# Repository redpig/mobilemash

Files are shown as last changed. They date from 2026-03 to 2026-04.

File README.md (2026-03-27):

# MobileMash - ESP32 Phone Button Presser

A 3D-printable, ESP32-controlled servo harness for programmatically pressing
phone buttons. Primary use case: booting phones into fastboot mode unattended.

## Supported Phones

| Phone | Status |
|---|---|
| Pixel 10 Pro | v1 |

## How It Works

Two SG90 micro servos are mounted in a 3D-printed cradle that clips around the
phone. Each servo has a small arm that presses a button (power, volume-down).
An ESP32 dev board drives the servos and accepts commands over USB serial.

### Fastboot Sequence

1. **Force shutdown** - Press and hold power for up to 30 seconds (or until
   told to release).
2. **Enter fastboot** - Hold volume-down, then briefly press power. Release
   when told or after a safety timeout.

## Hardware BOM

| Part | Qty | Notes |
|---|-----|---|
| ESP32 DevKit v1 (or similar) | 1 | Any ESP32 board with USB |
| SG90 micro servo | 2 | 9g, 180-degree |
| M2x8 self-tapping screws | 4 | Mount servos to cradle |
| Rubber/silicone bumper pads | 2 | Glue to servo arms for grip |
| USB-A to micro-USB cable | 1 | Power + data to ESP32 |
| 470uF electrolytic capacitor | 1 | Optional, across servo 5V/GND |

## Wiring

```
ESP32 GPIO 13 --> Power servo signal (orange)
ESP32 GPIO 14 --> Volume-down servo signal (orange)
ESP32 5V      --> Both servo VCC (red)
ESP32 GND     --> Both servo GND (brown)
```

## Firmware

Built with PlatformIO (Arduino framework).

```bash
cd firmware
pio run -t upload
```

### Serial Protocol (115200 baud)

Commands are newline-terminated ASCII:

| Command | Description |
|---|---|
| `PRESS_POWER <ms>` | Press power button for `<ms>` milliseconds |
| `PRESS_VOLDN <ms>` | Press volume-down for `<ms>` milliseconds |
| `FASTBOOT [shutdown_ms] [combo_ms]` | Run full fastboot entry sequence |
| `RELEASE_ALL` | Immediately release all buttons |
| `STATUS` | Report current state |
| `PING` | Returns `PONG` |

Responses are newline-terminated:

| Response | Meaning |
|---|---|
| `OK <detail>` | Command accepted / completed |
| `ERR <detail>` | Error |
| `STATE <json>` | Status response |
| `PONG` | Ping reply |

## 3D Printing

OpenSCAD source in `cad/`. Export STL and print with:
- Material: PLA or PETG
- Layer height: 0.2mm
- Infill: 20%+
- Supports: not required

## Host Tool

```bash
pip install pyserial
python host/mobilemash_cli.py --port /dev/ttyUSB0 fastboot
```

## License

Apache 2.0

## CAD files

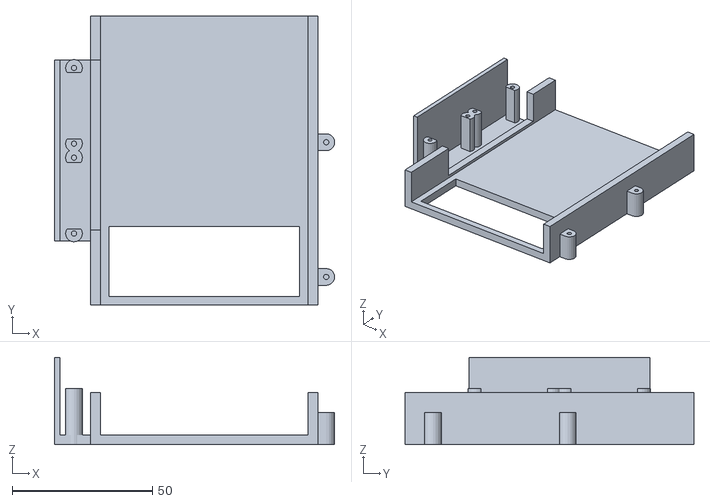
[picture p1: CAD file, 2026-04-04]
cad/pixel10pro_cradle.stl
99.9 x 103.0 x 31.1

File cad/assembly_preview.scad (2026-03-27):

/*
 * Assembly preview — cradle + phone + servos + ESP32
 * Uses $t (0–1) for animation rotation.
 */

use <pixel10pro_cradle.scad>

phone_w = 72; phone_h = 152.8; phone_d = 8.6;
clearance = 1.0; wall = 3.5; lip_h = 15;
cradle_len = 90; cradle_y_offset = 20;

sg90_body_w = 22.7; sg90_body_d = 11.8; sg90_body_h = 22.2;
sg90_tab_w = 32.5; sg90_tab_h = 2.5; sg90_shaft_offset = 6;
sg90_flipped_tab_z = 6.7; sg90_arm_drop = 4; sg90_shaft_protrusion = 5;
sg90_screw_spacing = 27;

inner_w = phone_w + 2 * clearance;
outer_w = inner_w + 2 * wall;
wall_top = wall + lip_h;

power_btn_y = 40; voldn_btn_y = 60;

arm_z = wall + phone_d / 2;
servo_bottom_z = arm_z + sg90_arm_drop;
boss_height = servo_bottom_z + sg90_flipped_tab_z;
boss_x = -(sg90_body_d / 2);

module phone() {
    color([0.15, 0.15, 0.15, 0.7])
        translate([wall + clearance, -cradle_y_offset, wall])
            cube([phone_w, phone_h, phone_d]);
    color([0.1, 0.1, 0.1, 0.8])
        translate([wall + clearance + 2, -cradle_y_offset + 10, wall - 3])
            cube([phone_w - 4, 26, 3]);
}

module sg90_servo(btn_y) {
    local_y = btn_y - cradle_y_offset;
    tab_z = servo_bottom_z + sg90_flipped_tab_z;

    // Body sits outside the left wall
    servo_x = -sg90_body_d;
    shaft_x = servo_x + sg90_body_d / 2;
    shaft_y = local_y;

    // Body below tabs
    color([0.2, 0.4, 0.8, 0.85])
        translate([servo_x, local_y - sg90_body_w/2, servo_bottom_z])
            cube([sg90_body_d, sg90_body_w, sg90_flipped_tab_z]);

    // Body above tabs
    color([0.2, 0.4, 0.8, 0.85])
        translate([servo_x, local_y - sg90_body_w/2, tab_z + sg90_tab_h])
            cube([sg90_body_d, sg90_body_w,
                  sg90_body_h - sg90_flipped_tab_z - sg90_tab_h]);

    // Tab ears
    color([0.25, 0.45, 0.85, 0.85])
        for (dy = [local_y - sg90_tab_w/2, local_y + sg90_body_w/2])
            translate([servo_x, dy, tab_z])
                cube([sg90_body_d, (sg90_tab_w - sg90_body_w)/2, sg90_tab_h]);

    // Gear housing + shaft
    color([0.2, 0.4, 0.8])
        translate([shaft_x, shaft_y, servo_bottom_z - 2])
            cylinder(h = 2, d = 8, $fn = 20);
    color([1, 1, 1])
        translate([shaft_x, shaft_y, servo_bottom_z - sg90_shaft_protrusion])
            cylinder(h = 3, d = 5, $fn = 20);

    // Arm at button height — pointing toward phone (+X)
    arm_len = 17; press_angle = 30;
    color([1, 1, 1])
        translate([0, 0, arm_z - 1])
            hull() {
                translate([shaft_x, shaft_y, 0])
                    cylinder(h = 2, d = 4, $fn = 16);
                translate([shaft_x + arm_len * cos(press_angle),
                           shaft_y - arm_len * sin(press_angle), 0])
                    cylinder(h = 2, d = 3, $fn = 16);
            }
}

module esp32_board() {
    board_x = outer_w + 3 - 25;
    color([0.0, 0.5, 0.0, 0.85])
        translate([outer_w + 3 - 14, 10, wall + 8]) cube([28, 55, 1.6]);
    color([0.7, 0.7, 0.7])
        translate([outer_w + 3 - 5, 10 - 1, wall + 9.6]) cube([10, 8, 3.5]);
    color([0.7, 0.7, 0.7])
        translate([outer_w + 3 - 10, 10 + 36, wall + 9.6]) cube([18, 16, 3]);
}

rot = $t * 360;
rotate([0, 0, rot])
translate([-outer_w / 2, -cradle_len / 2, -wall_top / 2]) {
    mobilemash_cradle();
    phone();
    sg90_servo(power_btn_y);
    sg90_servo(voldn_btn_y);
    esp32_board();
}

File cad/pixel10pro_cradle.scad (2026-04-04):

/*
 * MobileMash – 3D-printable cradle for Pixel 10 Pro
 *
 * Two SG90 micro servos mount UPSIDE-DOWN (shaft pointing down) on
 * screw bosses outside the LEFT wall (phone is face-down, so the
 * right-side buttons face the left wall).
 *
 * A base shelf at tray level connects the bosses to the wall.
 * Boss height is calculated so the servo arm sweeps in XY at
 * phone-button height.
 *
 * No print supports needed.  Sits flat.
 *
 * Phone dimensions (Pixel 10 Pro):
 *   152.8 x 72 x 8.6 mm
 *   Camera bump: 3 mm protrusion, starts 10 mm from top, ~25 mm tall,
 *                2 mm inset from each side edge.
 *
 * Button layout (right side of phone, measured from top):
 *   Power button center:      ~50 mm from top
 *   Volume-down button center: ~78 mm from top (50 + 28)
 *
 * SG90 servo body: 22.2 x 11.8 x 22.7 mm  (h x d x w)
 * SG90 mounting tabs: 32.5 mm total (tab-to-tab along body w)
 * SG90 screw hole spacing: 27 mm (measured)
 * Measured: 13 mm from tab screw-hole center to shaft tip.
 *
 * Print settings:
 *   Layer height: 0.2 mm
 *   Infill: 20%+
 *   Material: PLA or PETG
 *   Supports: NOT needed
 *
 * SPDX-License-Identifier: Apache-2.0
 */

// ── Tunables ────────────────────────────────────────────────────────────

phone_w   = 72;
phone_h   = 152.8;
phone_d   = 8.6;

clearance = 1.0;

wall = 3.5;
lip_h = 15;

cradle_y_offset = 7;   // start 7 mm from phone top to fully enclose camera bump
cradle_len = 103;      // extended to maintain same coverage at bottom

// ── Camera bump (Pixel 10 Pro) ──────────────────────────────────────────
cam_bump_protrusion = 3;
cam_bump_from_top   = 10;
cam_bump_height     = 25;
cam_bump_inset      = 2;
cam_bump_y_start = max(0, cam_bump_from_top - cradle_y_offset);
cam_bump_y_end   = cam_bump_from_top + cam_bump_height - cradle_y_offset;
cam_bump_w       = phone_w - 2 * cam_bump_inset;

// ── SG90 servo dimensions ───────────────────────────────────────────────
sg90_body_w  = 22.7;
sg90_body_d  = 11.8;
sg90_body_h  = 22.2;
sg90_tab_w   = 32.5;
sg90_tab_h   = 2.5;
sg90_shaft_offset = 6;

sg90_flipped_tab_z = 6.7;
sg90_shaft_protrusion = 5;
sg90_arm_drop = 4;

sg90_screw_spacing = 27;

// Button positions from top of phone.
power_btn_y = 50;
voldn_btn_y = 78;

// Shift the power servo mount toward the top (lower Y) so both
// screw bosses have room.
power_mount_shift = -4;

m2_hole_d = 1.9;     // tighter hole for better screw grip
boss_d = 6;

// ── Derived values ──────────────────────────────────────────────────────
inner_w = phone_w + 2 * clearance;
outer_w = inner_w + 2 * wall;
wall_top = wall + lip_h;

arm_z = wall + phone_d / 2;
servo_bottom_z = arm_z + sg90_arm_drop;

// Boss height: +1.5 mm per user feedback.
boss_height = servo_bottom_z + sg90_flipped_tab_z + 1.5;

boss_x = -(sg90_body_d / 2);

// Clearance between boss inner face and servo body edge.
// Body is 22.7 mm; with 27 mm boss spacing, each boss inner face
// must be at least 22.7/2 = 11.35 mm from center.  Add 0.5 mm gap.
boss_inner_clearance = sg90_body_w / 2 + 0.5;  // 11.85 mm from servo center

// ── Modules ─────────────────────────────────────────────────────────────

module cradle_base() {
    difference() {
        cube([outer_w, cradle_len, wall_top]);

        translate([wall, -0.1, wall])
            cube([inner_w, cradle_len + 0.2, lip_h + 1]);

        // Camera bump through-hole — fully enclosed by base material on
        // all four sides.  Phone drops in from above; the bump passes
        // through the hole and the surrounding edges retain the phone
        // on both X and Y axes.
        if (cam_bump_y_end > cam_bump_y_start) {
            translate([wall + clearance + cam_bump_inset,
                       cam_bump_y_start,
                       -0.1])
                cube([cam_bump_w,
                      cam_bump_y_end - cam_bump_y_start,
                      wall + 0.2]);
        }
    }
}

module servo_cutout(btn_y) {
    local_y = btn_y - cradle_y_offset;
    cutout_half = sg90_tab_w / 2;

    translate([-0.1,
               local_y - cutout_half,
               arm_z - 3])
        cube([wall + 0.2,
              sg90_tab_w,
              wall_top - (arm_z - 3) + 0.1]);
}

// D-shaped boss: cylinder with the inner face cut flat so the
// servo body (22.7 mm) fits between the two bosses.
module d_boss(center_y, mount_center_y) {
    is_lower = (center_y < mount_center_y);
    // Cut plane: inner face at boss_inner_clearance from mount center
    cut_y = is_lower
        ? mount_center_y - boss_inner_clearance
        : mount_center_y + boss_inner_clearance;

    difference() {
        translate([boss_x, center_y, 0])
            cylinder(h = boss_height, d = boss_d, $fn = 20);

        // Cut the inner half to make a flat face
        if (is_lower) {
            translate([boss_x - boss_d, cut_y, -0.1])
                cube([boss_d * 2, boss_d, boss_height + 0.2]);
        } else {
            translate([boss_x - boss_d, center_y - boss_d/2, -0.1])
                cube([boss_d * 2, cut_y - (center_y - boss_d/2), boss_height + 0.2]);
        }
    }
}

module servo_mount(btn_y, mount_shift=0) {
    local_y = btn_y - cradle_y_offset + mount_shift;

    // Base shelf — extends to meet the back wall
    shelf_x_start = boss_x - 5 - 2;  // align with back wall outer edge
    shelf_w = 0 - shelf_x_start;

    translate([shelf_x_start,
               local_y - sg90_tab_w / 2,
               0])
        cube([shelf_w, sg90_tab_w, wall]);

    // D-shaped screw bosses
    for (hole_y = [local_y - sg90_screw_spacing / 2,
                   local_y + sg90_screw_spacing / 2]) {
        d_boss(hole_y, local_y);
    }
}

module servo_mount_holes(btn_y, mount_shift=0) {
    local_y = btn_y - cradle_y_offset + mount_shift;

    for (hole_y = [local_y - sg90_screw_spacing / 2,
                   local_y + sg90_screw_spacing / 2]) {
        translate([boss_x, hole_y, boss_height - 8])
            cylinder(h = 8.1, d = m2_hole_d, $fn = 20);
    }
}

// Back wall behind each servo to resist torque that pulls
// the servo away from the cradle wall.
module servo_back_wall(btn_y, mount_shift=0) {
    local_y = btn_y - cradle_y_offset + mount_shift;
    back_w = sg90_tab_w;
    back_t = 2;          // thickness
    back_h = boss_height + sg90_body_h / 2; // extend up behind servo

    // Position inner face 5 mm from boss hole center (in X, away from wall)
    back_x = boss_x - 5;
    translate([back_x - back_t,
               local_y - back_w / 2,
               0])
        cube([back_t, back_w, back_h]);
}

module esp32_mount() {
    for (dy = [10, 58]) {
        translate([outer_w + 3, dy, 0])
            difference() {
                union() {
                    cylinder(h = wall + 8, d = 6, $fn = 20);
                    translate([-3, -3, 0])
                        cube([3, 6, wall + 8]);
                }
                translate([0, 0, wall])
                    cylinder(h = 9, d = m2_hole_d, $fn = 20);
            }
    }
}

// ── Assembly ────────────────────────────────────────────────────────────

module mobilemash_cradle() {
    difference() {
        union() {
            cradle_base();
            servo_mount(power_btn_y, power_mount_shift);
            servo_mount(voldn_btn_y);
            servo_back_wall(power_btn_y, power_mount_shift);
            servo_back_wall(voldn_btn_y);
            esp32_mount();
        }

        servo_cutout(power_btn_y);
        servo_cutout(voldn_btn_y);

        servo_mount_holes(power_btn_y, power_mount_shift);
        servo_mount_holes(voldn_btn_y);
    }
}

mobilemash_cradle();

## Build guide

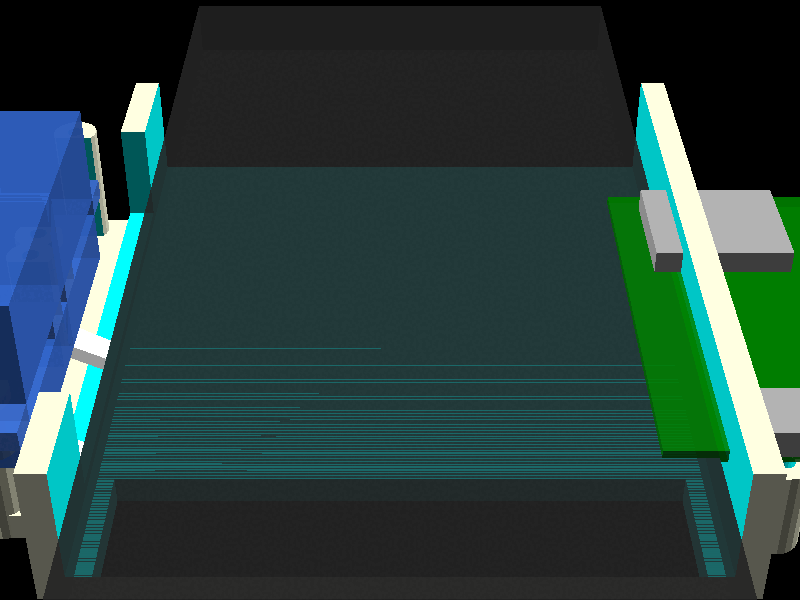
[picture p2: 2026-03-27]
cad/assembly_preview.gif

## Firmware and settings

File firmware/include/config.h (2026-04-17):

#pragma once

// ---------- Servo GPIO pins ----------
#define PIN_SERVO_POWER   13
#define PIN_SERVO_VOLDN   14

// ---------- Servo angles (degrees) ----------
// "Released" = arm is away from the button.
// "Pressed"  = arm pushes the button.
// Tune these per-build until the arm cleanly presses the button.
#define ANGLE_POWER_RELEASED  0
#define ANGLE_POWER_PRESSED   75

#define ANGLE_VOLDN_RELEASED  0
#define ANGLE_VOLDN_PRESSED   55

// ---------- Timing defaults (ms) ----------
#define DEFAULT_SHUTDOWN_HOLD_MS   45000   // 45 s power hold for force-off
#define DEFAULT_FASTBOOT_COMBO_MS   5000   // 5 s vol-down + power tap
#define POWER_TAP_MS                1000   // brief power press in combo
#define SAFETY_TIMEOUT_MS          60000   // hard cap on any single hold

// ---------- Serial ----------
#define SERIAL_BAUD  115200

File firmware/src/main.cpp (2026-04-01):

/*
 * MobileMash – ESP32 phone-button presser firmware
 *
 * Drives two SG90 servos (power button, volume-down button) via simple
 * ASCII commands over USB serial.  Primary use case: programmatic fastboot
 * entry for Pixel phones.
 *
 * SPDX-License-Identifier: Apache-2.0
 */

#include <Arduino.h>
#include <ESP32Servo.h>
#include "config.h"

// ── Servos ──────────────────────────────────────────────────────────────
Servo servoPower;
Servo servoVolDn;

static bool powerPressed = false;
static bool volDnPressed = false;

// ── Helpers ─────────────────────────────────────────────────────────────

static void pressPower() {
    servoPower.write(ANGLE_POWER_PRESSED);
    powerPressed = true;
}
static void releasePower() {
    servoPower.write(ANGLE_POWER_RELEASED);
    powerPressed = false;
}
static void pressVolDn() {
    servoVolDn.write(ANGLE_VOLDN_PRESSED);
    volDnPressed = true;
}
static void releaseVolDn() {
    servoVolDn.write(ANGLE_VOLDN_RELEASED);
    volDnPressed = false;
}
static void releaseAll() {
    releasePower();
    releaseVolDn();
}

// Block while holding, but keep reading serial for an early-release command.
// Returns true if we were interrupted by RELEASE_ALL, false if the duration
// expired normally.
static bool holdWithInterrupt(unsigned long durationMs) {
    unsigned long start = millis();
    while (millis() - start < durationMs) {
        if (Serial.available()) {
            String line = Serial.readStringUntil('\n');
            line.trim();
            if (line == "RELEASE_ALL") {
                releaseAll();
                Serial.println("OK RELEASE_ALL (interrupted hold)");
                return true;
            }
        }
        delay(10);
    }
    return false;
}

// ── Command handlers ────────────────────────────────────────────────────

static void cmdPressButton(void (*press)(), void (*release)(),
                           const char *name, unsigned long ms) {
    if (ms == 0 || ms > SAFETY_TIMEOUT_MS) {
        Serial.printf("ERR duration out of range (1-%lu)\n", SAFETY_TIMEOUT_MS);
        return;
    }
    Serial.printf("OK pressing %s for %lu ms\n", name, ms);
    press();
    bool interrupted = holdWithInterrupt(ms);
    if (!interrupted) {
        release();
        Serial.printf("OK released %s\n", name);
    }
}

static void cmdFastboot(unsigned long shutdownMs, unsigned long comboMs) {
    if (shutdownMs > SAFETY_TIMEOUT_MS) shutdownMs = SAFETY_TIMEOUT_MS;
    if (comboMs > SAFETY_TIMEOUT_MS)    comboMs    = SAFETY_TIMEOUT_MS;

    // Phase 1: force-shutdown by holding power
    Serial.printf("OK FASTBOOT phase1: holding power %lu ms\n", shutdownMs);
    pressPower();
    bool interrupted = holdWithInterrupt(shutdownMs);
    if (interrupted) return;
    releasePower();
    Serial.println("OK FASTBOOT phase1 done (power released)");

    // Brief pause to let the phone fully shut down
    delay(1000);

    // Phase 2: hold volume-down, then tap power
    // Stagger servo movements and detach vol-down PWM before moving power
    // to avoid brownout from simultaneous current draw.  The vol-down servo
    // holds its position via gear friction while unpowered.
    Serial.printf("OK FASTBOOT phase2: vol-down + power tap (%lu ms window)\n",
                  comboMs);
    pressVolDn();
    delay(500);            // hold vol-down for 500ms before moving power
    servoVolDn.detach();   // stop PWM — servo holds via friction
    delay(100);
    pressPower();

    unsigned long tapStart = millis();

    // Keep power pressed for POWER_TAP_MS or until interrupted
    while (millis() - tapStart < POWER_TAP_MS) {
        if (Serial.available()) {
            String line = Serial.readStringUntil('\n');
            line.trim();
            if (line == "RELEASE_ALL") {
                servoVolDn.attach(PIN_SERVO_VOLDN, 500, 2400);
                releaseAll();
                Serial.println("OK RELEASE_ALL (fastboot interrupted)");
                return;
            }
        }
        delay(10);
    }
    releasePower();  // release power after tap
    Serial.println("OK FASTBOOT power released, holding vol-down 5000 ms");

    // Re-attach vol-down and keep holding it for 5000ms after power release
    servoVolDn.attach(PIN_SERVO_VOLDN, 500, 2400);
    pressVolDn();  // re-assert vol-down now that power servo is idle

    bool postHoldInterrupted = holdWithInterrupt(5000);

    if (!postHoldInterrupted) {
        releaseAll();
        Serial.println("OK FASTBOOT complete");
    }
}

static void cmdStatus() {
    Serial.printf("STATE {\"power\":%s,\"voldn\":%s}\n",
                  powerPressed ? "true" : "false",
                  volDnPressed ? "true" : "false");
}

// ── Parse & dispatch ────────────────────────────────────────────────────

static unsigned long parseULong(const String &s, unsigned long defaultVal) {
    if (s.length() == 0) return defaultVal;
    return strtoul(s.c_str(), nullptr, 10);
}

static void processLine(String &line) {
    line.trim();
    if (line.length() == 0) return;

    if (line == "PING") {
        Serial.println("PONG");
        return;
    }
    if (line == "STATUS") {
        cmdStatus();
        return;
    }
    if (line == "RELEASE_ALL") {
        releaseAll();
        Serial.println("OK RELEASE_ALL");
        return;
    }

    // Commands with arguments: split on first space
    int sp = line.indexOf(' ');
    String cmd = (sp > 0) ? line.substring(0, sp) : line;
    String arg = (sp > 0) ? line.substring(sp + 1) : "";
    arg.trim();

    if (cmd == "PRESS_POWER") {
        unsigned long ms = parseULong(arg, 0);
        if (ms == 0) { Serial.println("ERR usage: PRESS_POWER <ms>"); return; }
        cmdPressButton(pressPower, releasePower, "power", ms);
    } else if (cmd == "PRESS_VOLDN") {
        unsigned long ms = parseULong(arg, 0);
        if (ms == 0) { Serial.println("ERR usage: PRESS_VOLDN <ms>"); return; }
        cmdPressButton(pressVolDn, releaseVolDn, "voldn", ms);
    } else if (cmd == "FASTBOOT") {
        // FASTBOOT [shutdown_ms] [combo_ms]
        unsigned long shutMs  = DEFAULT_SHUTDOWN_HOLD_MS;
        unsigned long comboMs = DEFAULT_FASTBOOT_COMBO_MS;
        if (arg.length() > 0) {
            int sp2 = arg.indexOf(' ');
            if (sp2 > 0) {
                shutMs  = parseULong(arg.substring(0, sp2), shutMs);
                comboMs = parseULong(arg.substring(sp2 + 1), comboMs);
            } else {
                shutMs = parseULong(arg, shutMs);
            }
        }
        cmdFastboot(shutMs, comboMs);
    } else if (cmd == "ANGLE_POWER") {
        int a = arg.toInt();
        if (a < 0 || a > 180) { Serial.println("ERR angle 0-180"); return; }
        servoPower.write(a);
        Serial.printf("OK power angle %d\n", a);
    } else if (cmd == "ANGLE_VOLDN") {
        int a = arg.toInt();
        if (a < 0 || a > 180) { Serial.println("ERR angle 0-180"); return; }
        servoVolDn.write(a);
        Serial.printf("OK voldn angle %d\n", a);
    } else {
        Serial.printf("ERR unknown command: %s\n", cmd.c_str());
    }
}

// ── Arduino entry points ────────────────────────────────────────────────

void setup() {
    Serial.begin(SERIAL_BAUD);
    while (!Serial) { delay(10); }

    ESP32PWM::allocateTimer(0);
    ESP32PWM::allocateTimer(1);

    servoPower.setPeriodHertz(50);
    servoVolDn.setPeriodHertz(50);

    servoPower.attach(PIN_SERVO_POWER, 500, 2400);
    servoVolDn.attach(PIN_SERVO_VOLDN, 500, 2400);

    releaseAll();

    Serial.println("OK MobileMash ready");
}

void loop() {
    if (Serial.available()) {
        String line = Serial.readStringUntil('\n');
        processLine(line);
    }
}

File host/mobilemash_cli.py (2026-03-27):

#!/usr/bin/env python3
"""
mobilemash_cli.py – Host-side CLI for MobileMash ESP32 button presser.

Requires: pyserial  (pip install pyserial)

Usage examples:
    python mobilemash_cli.py --port /dev/ttyUSB0 ping
    python mobilemash_cli.py --port /dev/ttyUSB0 fastboot
    python mobilemash_cli.py --port /dev/ttyUSB0 fastboot --shutdown-ms 30000 --combo-ms 5000
    python mobilemash_cli.py --port /dev/ttyUSB0 press-power 2000
    python mobilemash_cli.py --port /dev/ttyUSB0 release
    python mobilemash_cli.py --port /dev/ttyUSB0 status

SPDX-License-Identifier: Apache-2.0
"""

import argparse
import sys
import time

import serial


def open_serial(port: str, baud: int = 115200, timeout: float = 2.0) -> serial.Serial:
    """Open the serial port and wait for the ESP32 ready banner."""
    ser = serial.Serial(port, baud, timeout=timeout)
    # The ESP32 resets on serial open; wait for the ready line.
    deadline = time.monotonic() + 5.0
    while time.monotonic() < deadline:
        line = ser.readline().decode("utf-8", errors="replace").strip()
        if line:
            print(f"< {line}")
        if "MobileMash ready" in line:
            return ser
    # Even if we didn't see the banner, return the port – the device
    # may already have booted earlier.
    return ser


def send(ser: serial.Serial, cmd: str, wait_ok: bool = True,
         timeout: float = 120.0) -> list[str]:
    """Send a command and collect response lines until OK/ERR or timeout."""
    ser.reset_input_buffer()
    ser.write((cmd + "\n").encode("utf-8"))
    print(f"> {cmd}")

    lines: list[str] = []
    deadline = time.monotonic() + timeout
    while time.monotonic() < deadline:
        raw = ser.readline()
        if not raw:
            continue
        line = raw.decode("utf-8", errors="replace").strip()
        if not line:
            continue
        print(f"< {line}")
        lines.append(line)
        if not wait_ok:
            break
        # Terminal responses
        if line.startswith("OK ") or line.startswith("ERR ") or line == "PONG":
            # For multi-phase commands, "OK FASTBOOT complete" is terminal.
            if "complete" in line or "released" in line or line == "PONG":
                break
            if line.startswith("ERR "):
                break
    return lines


def cmd_ping(ser: serial.Serial, _args: argparse.Namespace) -> None:
    send(ser, "PING", timeout=5)


def cmd_status(ser: serial.Serial, _args: argparse.Namespace) -> None:
    send(ser, "STATUS", timeout=5)


def cmd_release(ser: serial.Serial, _args: argparse.Namespace) -> None:
    send(ser, "RELEASE_ALL", timeout=5)


def cmd_press_power(ser: serial.Serial, args: argparse.Namespace) -> None:
    send(ser, f"PRESS_POWER {args.ms}", timeout=(args.ms / 1000) + 10)


def cmd_press_voldn(ser: serial.Serial, args: argparse.Namespace) -> None:
    send(ser, f"PRESS_VOLDN {args.ms}", timeout=(args.ms / 1000) + 10)


def cmd_fastboot(ser: serial.Serial, args: argparse.Namespace) -> None:
    shutdown_ms = args.shutdown_ms
    combo_ms = args.combo_ms
    total_s = (shutdown_ms + combo_ms) / 1000 + 15
    send(ser, f"FASTBOOT {shutdown_ms} {combo_ms}", timeout=total_s)


def main() -> None:
    parser = argparse.ArgumentParser(
        description="MobileMash – ESP32 phone button presser CLI")
    parser.add_argument("--port", "-p", required=True,
                        help="Serial port (e.g. /dev/ttyUSB0)")
    parser.add_argument("--baud", type=int, default=115200)
    sub = parser.add_subparsers(dest="command", required=True)

    sub.add_parser("ping")
    sub.add_parser("status")
    sub.add_parser("release")

    pp = sub.add_parser("press-power")
    pp.add_argument("ms", type=int, help="Hold duration in milliseconds")

    pv = sub.add_parser("press-voldn")
    pv.add_argument("ms", type=int, help="Hold duration in milliseconds")

    fb = sub.add_parser("fastboot")
    fb.add_argument("--shutdown-ms", type=int, default=30000,
                     help="Power-hold duration for force shutdown (default 30000)")
    fb.add_argument("--combo-ms", type=int, default=5000,
                     help="Volume-down + power combo duration (default 5000)")

    args = parser.parse_args()

    ser = open_serial(args.port, args.baud)

    dispatch = {
        "ping": cmd_ping,
        "status": cmd_status,
        "release": cmd_release,
        "press-power": cmd_press_power,
        "press-voldn": cmd_press_voldn,
        "fastboot": cmd_fastboot,
    }
    dispatch[args.command](ser, args)
    ser.close()


if __name__ == "__main__":
    main()

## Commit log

2026-03-22 Fix servo shaft alignment and ESP32 mount spacing
    - Offset servo pocket/shelf/holes so the SG90 shaft (not body center)
    aligns with the button — fixes 5.35 mm misalignment that prevented
    the arm from reaching the button
    - Widen ESP32 mount posts from 40 mm to 48 mm apart for Elegoo DevKitV1
    - Connect tab shelves to right wall with vertical ribs above cable
    channel to eliminate floating geometry
    STL validates as 1 connected body, watertight, 0 non-manifold edges.
    [pixel10pro_cradle.scad, pixel10pro_cradle.stl]
2026-03-22 Fix tab shelf attachment and add assembly preview GIF
    - Remove vertical rib that blocked servo arms and snapped off
    - Instead, split cable channel to skip shelf zones so shelves bond
    directly through the full wall thickness
    - Add assembly_preview.scad with modeled phone, SG90 servos, and
    Elegoo ESP32 DevKitV1 for fit-check visualization
    - Render 36-frame animated GIF rotating around the full assembly
    [assembly_preview.scad, pixel10pro_cradle.scad, pixel10pro_cradle.stl]
2026-03-22 Add render_gif.sh script for assembly preview animation
    Usage: ./cad/render_gif.sh [frames] [output.gif]
    Requires openscad, xvfb-run, and imagemagick.
2026-03-23 Fix assembly preview: servo and ESP32 positioning
    - Servo bodies now sit in the wall pockets (starting at outer_w - wall)
    instead of floating outside the wall
    - Servo arms extend straight toward the phone, parallel to body
    - ESP32 board positioned entirely outside the left wall
    [assembly_preview.scad]
2026-03-23 Redesign servo mounting: flip upside-down for correct arm height
    The original design had the servo shaft at z≈24.7 (top of body), but
    phone buttons are at z≈6.8. The arm swept 13mm above the phone,
    missing the buttons entirely.
    Fix: mount servos upside-down so the shaft (and arm) is at the bottom
    at z = wall + phone_d/2 ≈ 6.8, matching the button height. The arm
    sweeps in XY at button height to press buttons. Servo bodies extend
    upward above the cradle wall.
    Updated assembly preview to show flipped servos with arms at the
    correct height.
    [assembly_preview.scad, pixel10pro_cradle.scad, pixel10pro_cradle.stl]
2026-03-23 Fix arm height, add camera bump relief, update from photo measurements
    - Raise servo body by sg90_arm_drop (3mm) to account for shaft protrusion
    below the gear housing — arm now sweeps at z=6.8 (mid-button) instead
    of z=3.8 (near the base floor)
    - Add camera bump relief cutout in the cradle base: 3mm deep through-hole
    for the Pixel 10 Pro camera visor (10mm from top, 26mm tall with margin,
    2mm inset from sides)
    - Dimensions verified against photo of actual SG90 servos on grid paper
    [assembly_preview.scad, pixel10pro_cradle.scad, pixel10pro_cradle.stl]
2026-03-23 Fix servo screw holes: vertical through shelf, not horizontal through wall
    SG90 tab screw holes are parallel to the shaft axis (Z), not
    perpendicular to the tab face (X). Horizontal wall screws can't
    engage them.
    - Widen tab shelf to span full body depth (wall + body_d + 2mm)
    - Add 5mm shelf depth below the tab for vertical M2 screw engagement
    - Drill pilot holes vertically (Z) through the shelf at tab positions
    - Remove old X-direction wall screw holes
    [pixel10pro_cradle.scad, pixel10pro_cradle.stl]
2026-03-23 Replace solid shelf with thin shelf + screw bosses to avoid body collision
    The 5mm-thick shelf occupied the same space as the servo body below the
    tabs. Now the shelf is only tab-thickness (2.5mm) as a resting surface,
    with separate cylindrical screw bosses (6mm dia, 5mm deep) at each tab
    ear position for vertical M2 screw engagement. Bosses are in the tab
    ear zones (outside the body Y range) so they don't block the body.
    [pixel10pro_cradle.scad, pixel10pro_cradle.stl]
2026-03-24 Update assembly preview to show servo body/shelf gap correctly
    Split the servo body model into above-tab and below-tab sections with
    visible tab ears, so the preview confirms no collision between the
    servo body and the thin shelf + screw bosses.
    [assembly_preview.scad]
2026-03-24 Update shaft protrusion to match measured 13mm tab-to-shaft distance
    User measured 13mm from tab screw hole center to shaft tip. Updated
    sg90_shaft_protrusion from 4→5mm and sg90_arm_drop from 3→4mm.
    Servo bottom raised to z=10.8 so arm stays at z=6.8 (mid-button).
    Clearances: shaft tip 3.3mm above base, arm 4.3mm above base,
    boss bottom 6.7mm above shaft tip.
    [assembly_preview.scad, pixel10pro_cradle.scad, pixel10pro_cradle.stl]
2026-03-24 Flip servo shelf to face up — no print supports, sits flat
    Shelf now sits ON TOP of the wall instead of hanging below. Servo
    tabs press up against the shelf underside; screws go down from above.
    Vertical support columns from the base hold up the cantilevered shelf
    portion — prints as simple pillars, no supports needed.
    - lip_h increased from 15→17.5 so wall_top = 20mm, placing the arm
    at z=6.8 (mid-button height)
    - Nothing protrudes below z=0; cradle sits flat on any surface
    - Min Z = 0, Max Z = 25 (shelf top)
    [assembly_preview.scad, pixel10pro_cradle.scad, pixel10pro_cradle.stl]
2026-03-24 Move servo shelf to base level — bosses go up, servo sits on top
    Shelf is now a base plate at z=0 (parallel with tray), with screw
    bosses rising 17.5mm to the wall top. Servo tabs rest on boss tops;
    screws go down through tabs into bosses.
    - lip_h back to 15 (wall_top = 17.5, flush with boss tops)
    - No overhangs, no supports, sits flat
    - Max Z = 17.5mm (no extra shelf on top)
    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
    [assembly_preview.scad, pixel10pro_cradle.scad, pixel10pro_cradle.stl]
2026-03-24 Merge servo pocket and arm slot into single cutout
    One continuous opening per servo from arm height to wall top, spanning
    the full tab width. Eliminates the separate pocket + window that was
    getting blocked by the adjacent servo's screw boss.
    [pixel10pro_cradle.scad, pixel10pro_cradle.stl]
2026-03-26 Remove cable routing channel — fixes floating wall strip
    The cable channel along the right wall bottom left a thin strip of
    wall barely connected below the servo cutouts. Removed it; servo
    wires can route through the cutout openings instead.
    [pixel10pro_cradle.scad, pixel10pro_cradle.stl]
2026-03-26 Extend ESP32 mount posts to base — no supports needed
    Posts now go from z=0 to z=wall+8 instead of floating at z=wall.
    Screw pilot holes still start at z=wall (above the base plate).
    [pixel10pro_cradle.scad, pixel10pro_cradle.stl]
2026-03-27 Move servos to left wall, thicken base, fix boss spacing
    1. Servos now mount on the LEFT wall (phone is face-down, so right-side
    buttons face the left wall). ESP32 moved to right wall.
    2. Base thickness increased from 2.5→3.5mm so the camera bump pocket
    (3mm deep) leaves 0.5mm of material instead of cutting through.
    3. Screw boss spacing changed from 28.5→27mm to match measured servo
    tab hole-to-hole distance.
    [assembly_preview.scad, pixel10pro_cradle.scad, pixel10pro_cradle.stl]
2026-03-27 Update button positions, fix camera bump pocket
    - Power button: 40→50mm from top (measured)
    - Volume-down: 60→78mm from top (50 + 28mm spacing, measured)
    - Camera bump pocket now cuts all the way through the base
    (removes the 0.5mm thin floor that was leaving extra material)
    [pixel10pro_cradle.scad, pixel10pro_cradle.stl]
2026-03-27 Add /mobilemash skill for serial servo control
    Slash command for sending commands to the ESP32 button presser:
    /mobilemash PRESS_POWER 500
    /mobilemash PRESS_VOLDN 1000
    /mobilemash RELEASE_ALL
    /mobilemash FASTBOOT
    /mobilemash PING
    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
2026-03-27 Add shorthand aliases to /mobilemash skill
    Now accepts: power, voldn, release, ping, status as shorthands.
    /mobilemash power → PRESS_POWER 500
    /mobilemash power 1000 → PRESS_POWER 1000
    /mobilemash voldn → PRESS_VOLDN 500
    /mobilemash release → RELEASE_ALL
2026-03-27 Raise bosses 1.5mm, shift power mount, D-shaped bosses for body fit
    1. Boss height +1.5mm (17.5→19.0mm) per user fit test feedback
    2. Power servo mount shifted 4mm toward top so both screw bosses
    have room
    3. Bosses now D-shaped (flat inner face) so the 22.7mm servo body
    fits between bosses at 27mm spacing — round bosses only left
    21mm gap, now 23.7mm with 0.5mm clearance per side
    [pixel10pro_cradle.scad, pixel10pro_cradle.stl]
2026-03-28 Tune servo angles and add ANGLE_POWER/ANGLE_VOLDN commands
    - Power pressed angle: 60→75° (tuned with physical test)
    - Volume-down pressed angle: 60→55° (tuned with physical test)
    - Add ANGLE_POWER <deg> and ANGLE_VOLDN <deg> commands for live
    angle tuning without reflashing
    - Set upload_port to /dev/ttyUSB1 for Elegoo ESP32 DevKitV1
2026-04-01 Fix brownout during fastboot by staggering servo movements
    Detach vol-down servo PWM before moving power servo to avoid
    simultaneous current draw that triggers ESP32 brownout reset.
    Also increase shutdown hold to 35s, power tap to 1000ms, and
    hold vol-down for 5s after power release for reliable fastboot entry.
    [config.h, main.cpp]
2026-04-04 Add top retention lip, servo back walls, and tighter boss holes
    Phone was sliding up under servo pressure — added a retention bar
    across the top edge. Servos were coming loose from mounts — added
    back walls behind each servo to resist torque and reduced screw
    boss hole diameter from 2.2mm to 1.9mm for better grip.
    [pixel10pro_cradle.scad, pixel10pro_cradle.stl]
2026-04-04 Fix servo back wall position (5mm from boss) and camera pocket (24mm)
    Move back wall inner face to 5mm from screw boss center for proper
    servo retention. Extend shelf to meet back wall. Correct camera bump
    pocket height from 26mm to 24mm.
    [pixel10pro_cradle.scad, pixel10pro_cradle.stl]
2026-04-04 Remove top retention lip, extend back wall, bump pocket to 25mm
    Camera bump pocket in the base is sufficient to retain the phone.
    Extend servo back walls to half the servo body height above the
    boss for better torque resistance. Camera pocket now 25mm.
    [pixel10pro_cradle.scad, pixel10pro_cradle.stl]
2026-04-04 Add bridge at top of camera notch to retain phone
    Camera bump through-cut now starts one wall-thickness (3.5mm) below
    the top edge of the cradle, leaving a bridge that the camera bump
    can't pass through. Phone slides in from the bottom and is trapped.
    [pixel10pro_cradle.scad, pixel10pro_cradle.stl]
2026-04-04 Fix camera notch to 24.5mm so bump fits and bridge retains phone
    The through-cut was only 11.5mm due to cradle clipping. Now the
    notch is a fixed 24.5mm with a 3.5mm bridge at the top — the 25mm
    camera bump fits through but can't pass the bridge.
    [pixel10pro_cradle.scad, pixel10pro_cradle.stl]
2026-04-04 Extend cradle to fully enclose camera bump notch for phone retention
    Extended cradle upward (y_offset 20->7mm, len 90->103mm) so the
    camera bump through-hole is fully surrounded by base material on
    all four sides. Phone drops in from above and is retained on both
    X and Y axes by the notch edges. 3mm bridge at top, 25mm hole.
    [pixel10pro_cradle.scad, pixel10pro_cradle.stl]
2026-04-14 Fix servo brownout by detaching after move and disabling brownout detector
    Servos now attach, move, settle, then detach after each movement so they
    never draw simultaneous holding current. Phase 2 fastboot uses slow-ramp
    for power servo while vol-down stays attached. Brownout detector disabled
    to ride through voltage dips on USB power. Vol-down angle increased to 65
    degrees to compensate for post-detach relaxation.
    [config.h, main.cpp]
2026-04-14 Remove brownout bypass and angle overcorrection, use dedicated power supply
    With a separate 5V power supply for the servos, we no longer need the
    brownout detector bypass or the 65-degree angle overcorrection. Both
    servos now stay attached with active PWM during fastboot phase 2.
    [config.h, main.cpp]
2026-04-15 Revert brownout workarounds now that servos have dedicated power supply, add flash script
    Remove moveAndDetach, slowMove, staggered delays, and attachAndHold — servos
    stay attached and use direct write() calls. Restore original timing defaults
    (30s shutdown, 500ms power tap). Add firmware/flash.sh for convenient builds.
    [config.h, main.cpp]
2026-04-17 Increase shutdown hold to 45s and restore staggered Phase 2 servo handling
    Power servo needs ~5s to fully engage on boot, so 30s wasn't leaving
    enough effective hold time for force-shutdown. Bumped to 45s. Restored
    the 947cbb2 Phase 2 approach: stagger servos (detach vol-down before
    pressing power) and use 1s power tap to avoid simultaneous current draw.
    [config.h, main.cpp]
